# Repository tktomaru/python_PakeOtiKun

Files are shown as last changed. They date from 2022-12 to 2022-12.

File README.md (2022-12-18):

# パケ落ちくんとは？

パケ落ちくんはネットワークエミュレーターです。
Lanの途中に挟むことで、ネットワークに対し以下のことができます。

- 遅延(DELAY)
- 廃棄(LOSS)
- 破壊(CORRUPT) : PakeOtiKun4とPakeOtiKunRSが対応
- 重複(DUPLICATION) : PakeOtiKun4とPakeOtiKunRSが対応
- 並び替え(REORDERING) : PakeOtiKunRSが対応

# ブログ

# パケ落ちくんソースコード

- PakeOtiKun.py : DSAS様の作成されたものと同じものをpythonにしました
- PakeOtiKun4.py : PakeOtiKunにおいて可変抵抗が2つだったものを4つにしたものです
- PakeOtiKunRS.py : 可変抵抗は4つでロータリースイッチを追加したものです

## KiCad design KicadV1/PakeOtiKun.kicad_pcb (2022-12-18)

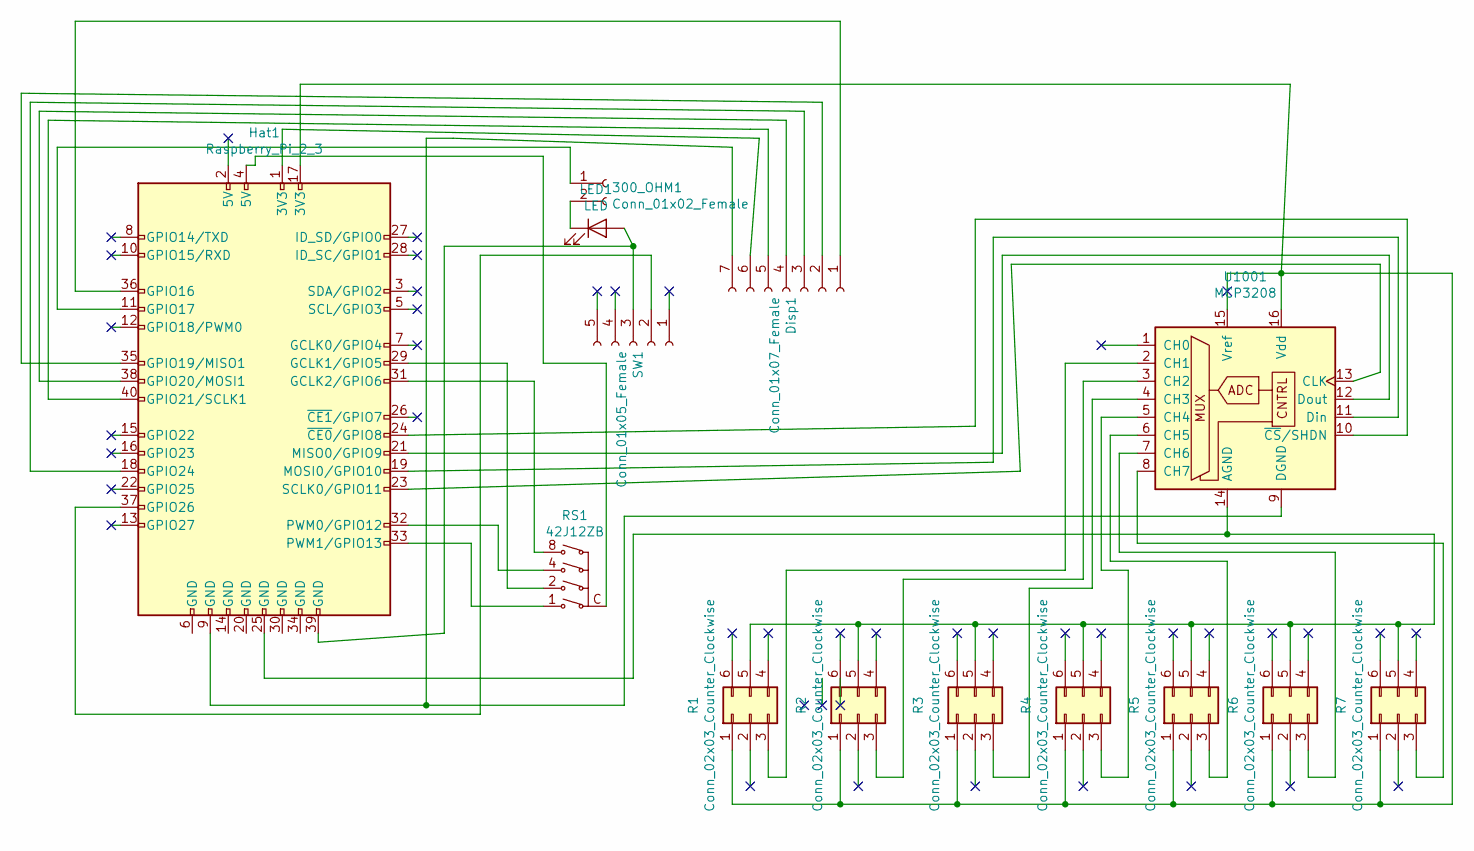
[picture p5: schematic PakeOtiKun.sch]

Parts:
300_OHM1: Conn_01x02_Female; PinSocket_1x02_P2.54mm_Vertical
Disp1: Conn_01x07_Female; PinSocket_1x07_P2.54mm_Vertical
Hat1: Raspberry_Pi_2_3; Raspi
LED1: LED; PinSocket_1x02_P2.54mm_Vertical
R1, R2, R3, R4, R5, R6, R7: Conn_02x03_Counter_Clockwise; PinSocket_2x03_P2.54mm_Vertical
RS1: 42J12ZB; RS
SW1: Conn_01x05_Female; PinSocket_1x05_P2.54mm_Vertical
U1001: MCP3208

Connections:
unnamed: 300_OHM1.1, Hat1.11 (GPIO17)
unnamed: 300_OHM1.2, LED1.1 (K)
unnamed: Disp1.1, Hat1.36 (GPIO16)
unnamed: Disp1.2, Hat1.35 (GPIO19/MISO1)
unnamed: Disp1.3, Hat1.18 (GPIO24)
unnamed: Disp1.4, Hat1.38 (GPIO20/MOSI1)
unnamed: Disp1.5, Hat1.40 (GPIO21/SCLK1)
unnamed: Disp1.6, Hat1.1 (3V3)
unnamed: Disp1.7, Hat1.9 (GND), U1001.9 (DGND)
unnamed: Hat1.4 (5V), RS1.C
unnamed: Hat1.17 (3V3), R1.1, R2.1, R3.1, R4.1, R5.1, R6.1, R7.1, U1001.15 (Vref), U1001.16 (Vdd)
unnamed: Hat1.19 (MOSI0/GPIO10), U1001.11 (Din)
unnamed: Hat1.21 (MISO0/GPIO9), U1001.12 (Dout)
unnamed: Hat1.23 (SCLK0/GPIO11), U1001.13 (CLK)
unnamed: Hat1.24 (~CE0~/GPIO8), U1001.10 (~CS~/SHDN)
unnamed: Hat1.25 (GND), R1.5, R2.5, R3.5, R4.5, R5.5, R6.5, R7.5, U1001.14 (AGND)
unnamed: Hat1.29 (GCLK1/GPIO5), RS1.2
unnamed: Hat1.31 (GCLK2/GPIO6), RS1.8
unnamed: Hat1.32 (PWM0/GPIO12), RS1.4
unnamed: Hat1.33 (PWM1/GPIO13), RS1.1
unnamed: Hat1.37 (GPIO26), SW1.2
unnamed: Hat1.39 (GND), LED1.2 (A), SW1.3
unnamed: R1.3, U1001.2 (CH1)
unnamed: R2.3, U1001.3 (CH2)
unnamed: R3.3, U1001.4 (CH3)
unnamed: R4.3, U1001.5 (CH4)
unnamed: R5.3, U1001.6 (CH5)
unnamed: R6.3, U1001.7 (CH6)
unnamed: R7.3, U1001.8 (CH7)

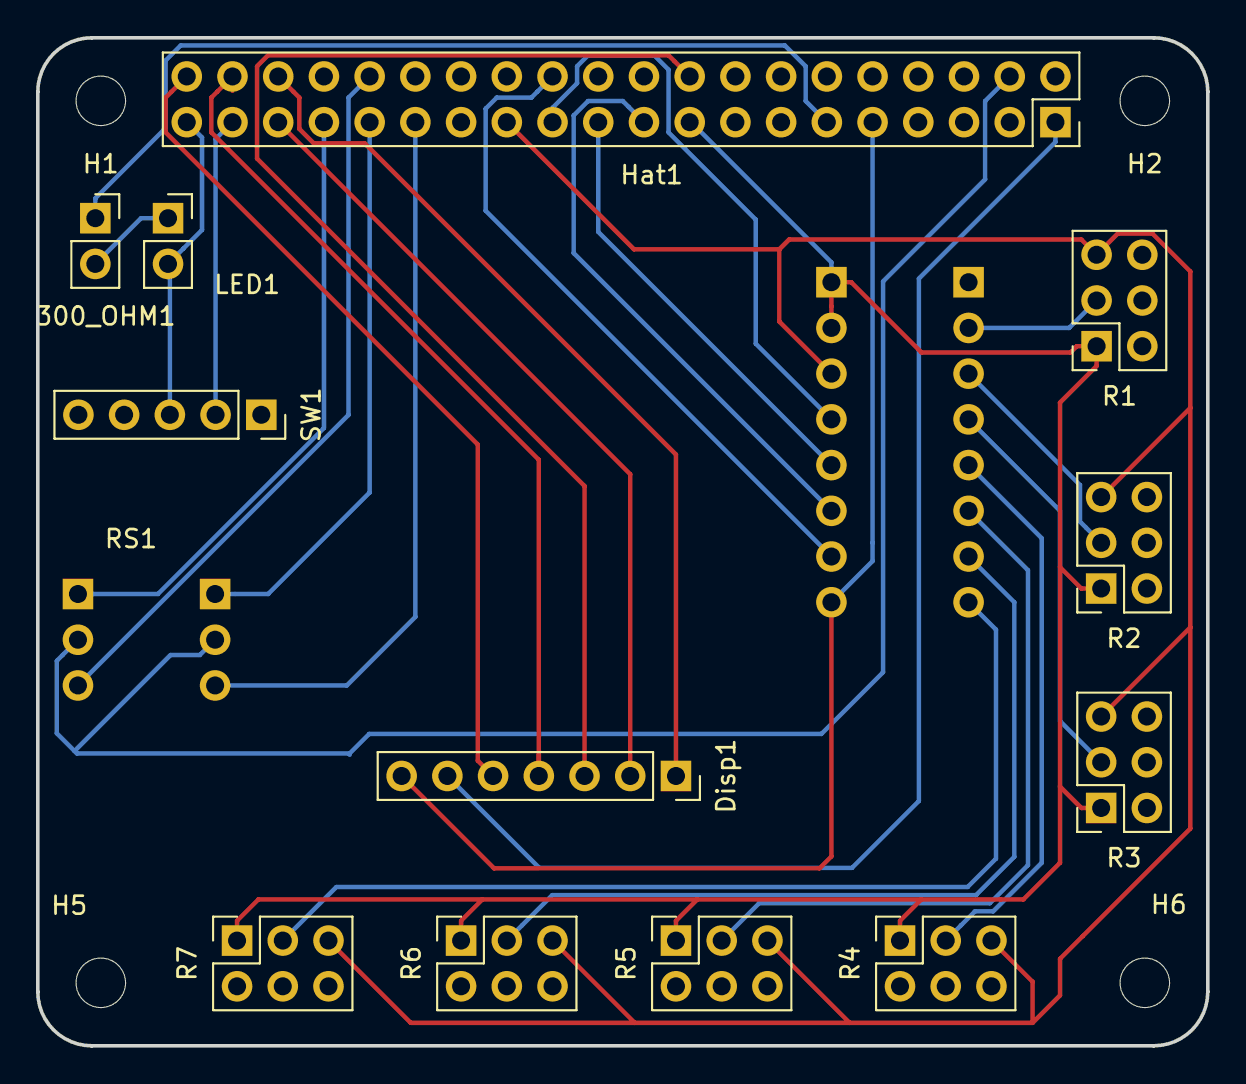
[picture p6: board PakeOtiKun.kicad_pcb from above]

Board: 2 copper layers, 65.0 x 56.0 mm, 18 parts (1 on the bottom side), 29 nets.

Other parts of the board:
H1, H2, H5, H6: MountingHole; MountingHole_2.75mm_NoPad

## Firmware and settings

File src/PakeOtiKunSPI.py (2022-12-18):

# -*- coding: utf-8 -*-
#!/usr/bin/env python

import RPi.GPIO as GPIO
import Adafruit_GPIO.SPI as SPI
import Adafruit_SSD1306
from PIL import Image, ImageDraw, ImageFont

import subprocess
import os,sys
import struct

import spidev
import time

# pip install Adafruit_GPIO  Adafruit_SSD1306 

###################################3

# SPI channel (0 or 1)
SPI_CH = 0

SPI_SS_AD = 7
SPI_SS_LCD = 8

# SPI speed (hz)
SPI_SPEED = 1000000

# GPIO number
PIN_LED = 17
PIN_SW  = 22
SW_ON   = 0

PIN_RS1 = 5
PIN_RS2 = 6
PIN_RS4 = 13
PIN_RS8 = 12

VOLUME_DELAY=0
VOLUME_LOSS =1
VOLUME_DUP=2
VOLUME_CORRUPT=3
VOLUME_REORDER1=4
VOLUME_REORDER2=5

####################################
before_delay = 0

####################################
# Raspberry Pi pin configuration
RST = 24
spi0 = SPI.SpiDev( 1, 2, max_speed_hz=SPI_SPEED)
spi0.set_mode(0)
disp = Adafruit_SSD1306.SSD1306_128_64(rst=RST, dc=19, spi=spi0)
#disp = Adafruit_SSD1306.SSD1306_128_32(rst=RST)

# Initialize library.
disp.begin()
 
# Create blank image for drawing.
# Make sure to create image with mode '1' for 1-bit color.
width = disp.width
height = disp.height
image = Image.new('1', (width, height))
 
draw = ImageDraw.Draw(image)

# Misaki Font, awesome 8x8 pixel Japanese font, can be downloaded from the following URL.
# $ wget http://www.geocities.jp/littlimi/arc/misaki/misaki_ttf_2015-04-10.zip
#font = ImageFont.truetype('/home/pi/font/misakifont/misaki_gothic.ttf', 12, encoding='unic')

# Un-comment out the following line if you want to use the default font instead of Misaki Font
font = ImageFont.load_default()

def tc_set (dev, delay, loss, dup, corrupt, reorder1, reorder2, rs):
    if rs == 1:
        if delay == 0:
           delay = 10
        cmd="sudo tc qdisc change dev %s root netem delay %dms loss %d%% reorder %d%% %d%% "%(dev, delay, loss, dup, corrupt)
    else:
        if delay == 0 and (reorder1 != 0 or reorder2 != 0):
            delay = 10
        cmd="sudo tc qdisc change dev %s root netem delay %dms loss %d%% duplicate %d%% corrupt %d%% reorder %d%% %d%%"%(dev, delay, loss, dup, corrupt, reorder1, reorder2)
    subprocess.call(cmd.split())

def tc_init (dev):
    cmd="sudo tc qdisc del dev %s root >/dev/null 2>&1"%(dev)
    subprocess.call(cmd.split())
    cmd="sudo tc qdisc add dev %s root netem delay 0ms loss 0%%"%(dev)
    subprocess.call(cmd.split())


def lcd_clear():
    # Clear display.
    #GPIO.output( SPI_SS_LCD, GPIO.LOW) 
    disp.clear()
    disp.display()
    #GPIO.output( SPI_SS_LCD, GPIO.HIGH) 

def lcd_write (delay, loss, dup, corrupt, select, reorder1, reorder2, rs):
    t1="delay %3d ms %3d %%"%(delay, reorder1)
    t2="loss  %3d %%  %3d %%"%(loss, reorder2)
    if rs == 0:
        t3="dup     %3d %%"%(dup)
    elif rs == 1:
        t3="reorder %3d %%"%(dup)
    else:
        t3="dup     %3d %%"%(dup)

    if rs == 0:
        t4="corrup  %3d %%"%(corrupt)
    elif rs == 1:
        t4="reorder %3d %%"%(corrupt)
    else:
        t4="corrup  %3d %%"%(corrupt)


    if select == 0:
        t1="delay %3d ms %3d %%"%(delay, reorder1)
    if select == 1:
        t2="loss  %3d %%  %3d %%"%(loss, reorder2)
    if select == 2:
        if rs == 0:
            t3="dup     %3d %%"%(dup)
        elif rs == 1:
            t3="reorder %3d %%"%(dup)
        else:
            t3="dup     %3d %%"%(dup)
    if select == 3:
        if rs == 0:
            t4="corrup  %3d %%"%(corrupt)
        elif rs == 1:
            t4="reorder %3d %%"%(corrupt)
        else:
            t4="corrup  %3d %%"%(corrupt)

    #GPIO.output( SPI_SS_LCD, GPIO.LOW) 
    image = Image.new('1', (width, height))
    draw = ImageDraw.Draw(image)

    x=0
    y=0
    draw.text((x,y), t1, font=font,  fill=255)
    y+=16
    draw.text((x,y), t2, font=font,  fill=255)
    y+=16
    draw.text((x,y), t3, font=font,  fill=255)
    y+=16
    draw.text((x,y), t4, font=font,  fill=255)

    disp.image(image)
    disp.display()
    #GPIO.output( SPI_SS_LCD, GPIO.HIGH) 

class MCP3208:
        def __init__(self, spi_channel=0):
                self.spi_channel = spi_channel
                self.conn = SPI.SpiDev(0, spi_channel, SPI_SPEED)
                self.conn.set_mode(0)
                self.conn.set_bit_order(SPI.MSBFIRST)
                #self.conn.max_speed_hz = SPI_SPEED # 1MHz

        def __del__( self ):
                self.close

        def close(self):
                if self.conn != None:
                        self.conn.close
                        self.conn = None

        def bitstring(self, n):
                s = bin(n)[2:]
                return '0'*(8-len(s)) + s

        def read(self, adc_channel=0):
                # build command
                cmd  = 128 # start bit
                cmd +=  64 # single end / diff
                cmd += ((adc_channel & 0x07) << 3)
                #if adc_channel % 2 == 1:
                #        cmd += 8
                #if (adc_channel/2) % 2 == 1:
                #        cmd += 16
                #if (adc_channel/4) % 2 == 1:
                #        cmd += 32

                # send & receive data
                #reply_bytes = self.conn.xfer2([cmd, 0, 0, 0])
                reply_bytes = self.conn.transfer([cmd, 0, 0, 0])

                #
                reply_bitstring = ''.join(self.bitstring(n) for n in reply_bytes)
                # print reply_bitstring

                # see also... http://akizukidenshi.com/download/MCP3204.pdf (page.20)
                #reply = reply_bitstring[5:19]
                #return int(reply, 2)
                reply = (reply_bytes[0] & 0x01) << 11
                reply |= reply_bytes[1] << 3
                reply |= reply_bytes[2] >> 5
                return (reply & 0x0FFF)

def RS_Analysis( rs1, rs2, rs4, rs8 ):
        rs = 0
        if rs1 == 0 and rs2 == 0 and rs4 == 0 and rs8 == 0 :
            rs = 0
        if rs1 == 1 and rs2 == 0 and rs4 == 0 and rs8 == 0 :
            rs = 1
        if rs1 == 0 and rs2 == 1 and rs4 == 0 and rs8 == 0 :
            rs = 2
        if rs1 == 1 and rs2 == 1 and rs4 == 0 and rs8 == 0 :
            rs = 3
        if rs1 == 0 and rs2 == 0 and rs4 == 1 and rs8 == 0 :
            rs = 4
        if rs1 == 1 and rs2 == 0 and rs4 == 1 and rs8 == 0 :
            rs = 5
        if rs1 == 0 and rs2 == 1 and rs4 == 1 and rs8 == 0 :
            rs = 6
        if rs1 == 1 and rs2 == 1 and rs4 == 1 and rs8 == 0 :
            rs = 7
        if rs1 == 0 and rs2 == 0 and rs4 == 0 and rs8 == 1 :
            rs = 8
        if rs1 == 1 and rs2 == 0 and rs4 == 0 and rs8 == 1 :
            rs = 9
        #print("RW")
        #print(rs)
        return rs

def hosei100( l ):
        l = round(++l / 2 / 20.47)
        if l < 3:
            l=0
        if l >= 98:
            l = 100
        return l

def hosei2000( l ):
        global before_delay
        l = round(++l / 2.048 ) # 4096
        # if ( l >= 3 and ((before_delay - 10) <= l) and (l <= (before_delay + 10 ))):
        # l = before_delay
        # else:
        #     before_delay = l
        if l < 3:
            l=0
        if l >= 1990:
            l=2000
        return l

def hosei2048( l ):
        l = round(++l / 2 )
        if l < 3:
            l=0
        return l

def burst_mode():
    for n in range(devnum):
        tc_set( devices[n], 0, 100, 0, 0, 0, 0, 0)
    lcd_clear()
    image = Image.new('1', (width, height))
    draw = ImageDraw.Draw(image)
    draw.text((0,0), "burst  mode  ", font=font,  fill=255)
    disp.image(image)
    disp.display()
    GPIO.output(PIN_LED,  1 )
    while True:
        #print("burst mode")
        sw=GPIO.input( PIN_SW )
        if sw != SW_ON:
            break
        #time.sleep(1)

if __name__=="__main__":
    spi = MCP3208(SPI_CH)

    # Write two lines of text.
    x=0
    y=0
    for str in [ u'booting' ]:
        draw.text((x,y), str, font=font,  fill=255)
        y+=16

    # rotate 180
    #disp.com(0xa0)
    #disp.com(0xc0)

    devices = ["eth0", "eth1"];
    devnum  = 2;
    for dev in devices:
        tc_init(dev)
    delay =  -1 # for display out
    loss = 0
    dup  = 0
    corrupt = 0
    grs = 0
    reorder1 = 0
    reorder2 = 0
    print("GPIO.setup LED")
    GPIO.setmode(GPIO.BCM)
    GPIO.setup( PIN_LED , GPIO.OUT )
    print("GPIO.setup SW")
    GPIO.setup( PIN_SW, GPIO.IN, pull_up_down=GPIO.PUD_UP )
    GPIO.setup( PIN_RS1, GPIO.IN )
    GPIO.setup( PIN_RS2, GPIO.IN )
    GPIO.setup( PIN_RS4, GPIO.IN )
    GPIO.setup( PIN_RS8, GPIO.IN )

    #time.sleep(2)

    while (1):
        sw=GPIO.input( PIN_SW )
        if sw == SW_ON:
            burst_mode()
            delay = -1 # for display out
        rs1=GPIO.input( PIN_RS1 )
        rs2=GPIO.input( PIN_RS2 )
        rs4=GPIO.input( PIN_RS4 )
        rs8=GPIO.input( PIN_RS8 )

        rs = RS_Analysis( rs1, rs2, rs4, rs8 )
        #print(rs)

        #print("delay >>")

        d = hosei2000( spi.read(VOLUME_DELAY)  )
        l = hosei100( spi.read(VOLUME_LOSS) )
        c = hosei100( spi.read(VOLUME_CORRUPT) )
        p = hosei100( spi.read(VOLUME_DUP) )
        r1 = hosei100( spi.read(VOLUME_REORDER1) )
        r2 = hosei100( spi.read(VOLUME_REORDER2) )

        if (d != delay):
           gselect = 0
        if (l != loss):
           gselect = 1
        if (p != dup):
           gselect = 2
        if (c != corrupt):
           gselect = 3

        if (d != delay or l != loss or p != dup or c != corrupt or r1 != reorder1 or r2 != reorder2 or rs != grs):
            delay = d
            loss = l
            dup = p
            corrupt = c
            grs = rs
            reorder1 = r1
            reorder2 = r2
            for n in range(devnum):
                tc_set(devices[n], delay, loss, dup, corrupt, reorder1, reorder2, grs)
            lcd_clear()
            lcd_write (delay, loss, dup, corrupt, gselect, reorder1, reorder2, grs)
        if delay != 0 or loss != 0 or dup != 0 or corrupt != 0 or reorder1 != 0 or reorder2 != 0:
            GPIO.output(PIN_LED,  1 )
        else:
            GPIO.output(PIN_LED,  0 )

       # time.sleep(2)

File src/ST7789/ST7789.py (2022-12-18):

# ST7789 IPS LCD (240x240) driver
import numbers
import time
import numpy as np

from PIL import Image
from PIL import ImageDraw

import Adafruit_GPIO as GPIO
import Adafruit_GPIO.SPI as SPI

SPI_CLOCK_HZ = 40000000 # 40 MHz

# Constants for interacting with display registers.
ST7789_TFTWIDTH    = 240
ST7789_TFTHEIGHT   = 240

ST7789_NOP         = 0x00
ST7789_SWRESET     = 0x01
ST7789_RDDID       = 0x04
ST7789_RDDST       = 0x09
ST7789_RDDPM       = 0x0A
ST7789_RDDMADCTL   = 0x0B
ST7789_RDDCOLMOD   = 0x0C
ST7789_RDDIM       = 0x0D
ST7789_RDDSM       = 0x0E
ST7789_RDDSDR      = 0x0F

ST7789_SLPIN       = 0x10
ST7789_SLPOUT      = 0x11
ST7789_PTLON       = 0x12
ST7789_NORON       = 0x13

ST7789_INVOFF      = 0x20
ST7789_INVON       = 0x21
ST7789_GAMSET      = 0x26
ST7789_DISPOFF     = 0x28
ST7789_DISPON      = 0x29
ST7789_CASET       = 0x2A
ST7789_RASET       = 0x2B
ST7789_RAMWR       = 0x2C
ST7789_RAMRD       = 0x2E

ST7789_PTLAR       = 0x30
ST7789_VSCRDEF     = 0x33
ST7789_TEOFF       = 0x34
ST7789_TEON        = 0x35
ST7789_MADCTL      = 0x36
ST7789_VSCRSADD    = 0x37
ST7789_IDMOFF      = 0x38
ST7789_IDMON       = 0x39
ST7789_COLMOD      = 0x3A
ST7789_RAMWRC      = 0x3C
ST7789_RAMRDC      = 0x3E

ST7789_TESCAN      = 0x44
ST7789_RDTESCAN    = 0x45

ST7789_WRDISBV     = 0x51
ST7789_RDDISBV     = 0x52
ST7789_WRCTRLD     = 0x53
ST7789_RDCTRLD     = 0x54
ST7789_WRCACE      = 0x55
ST7789_RDCABC      = 0x56
ST7789_WRCABCMB    = 0x5E
ST7789_RDCABCMB    = 0x5F

ST7789_RDABCSDR    = 0x68

ST7789_RDID1       = 0xDA
ST7789_RDID2       = 0xDB
ST7789_RDID3       = 0xDC

ST7789_RAMCTRL     = 0xB0
ST7789_RGBCTRL     = 0xB1
ST7789_PORCTRL     = 0xB2
ST7789_FRCTRL1     = 0xB3

ST7789_GCTRL       = 0xB7
ST7789_DGMEN       = 0xBA
ST7789_VCOMS       = 0xBB

ST7789_LCMCTRL     = 0xC0
ST7789_IDSET       = 0xC1
ST7789_VDVVRHEN    = 0xC2

ST7789_VRHS        = 0xC3
ST7789_VDVSET      = 0xC4
ST7789_VCMOFSET    = 0xC5
ST7789_FRCTR2      = 0xC6
ST7789_CABCCTRL    = 0xC7
ST7789_REGSEL1     = 0xC8
ST7789_REGSEL2     = 0xCA
ST7789_PWMFRSEL    = 0xCC

ST7789_PWCTRL1     = 0xD0
ST7789_VAPVANEN    = 0xD2
ST7789_CMD2EN      = 0xDF5A6902
ST7789_PVGAMCTRL   = 0xE0
ST7789_NVGAMCTRL   = 0xE1
ST7789_DGMLUTR     = 0xE2
ST7789_DGMLUTB     = 0xE3
ST7789_GATECTRL    = 0xE4
ST7789_PWCTRL2     = 0xE8
ST7789_EQCTRL      = 0xE9
ST7789_PROMCTRL    = 0xEC
ST7789_PROMEN      = 0xFA
ST7789_NVMSET      = 0xFC
ST7789_PROMACT     = 0xFE

# Colours for convenience
ST7789_BLACK       = 0x0000 # 0b 00000 000000 00000
ST7789_BLUE        = 0x001F # 0b 00000 000000 11111
ST7789_GREEN       = 0x07E0 # 0b 00000 111111 00000
ST7789_RED         = 0xF800 # 0b 11111 000000 00000
ST7789_CYAN        = 0x07FF # 0b 00000 111111 11111
ST7789_MAGENTA     = 0xF81F # 0b 11111 000000 11111
ST7789_YELLOW      = 0xFFE0 # 0b 11111 111111 00000
ST7789_WHITE       = 0xFFFF # 0b 11111 111111 11111


def color565(r, g, b):
    """Convert red, green, blue components to a 16-bit 565 RGB value. Components
    should be values 0 to 255.
    """
    return ((r & 0xF8) << 8) | ((g & 0xFC) << 3) | (b >> 3)

def image_to_data(image):
    """Generator function to convert a PIL image to 16-bit 565 RGB bytes."""
    # NumPy is much faster at doing this. NumPy code provided by:
    # Keith (https://www.blogger.com/profile/02555547344016007163)
    pb = np.array(image.convert('RGB')).astype('uint16')
    color = ((pb[:,:,0] & 0xF8) << 8) | ((pb[:,:,1] & 0xFC) << 3) | (pb[:,:,2] >> 3)
    return np.dstack(((color >> 8) & 0xFF, color & 0xFF)).flatten().tolist()

class ST7789(object):
    """Representation of an ST7789 IPS LCD."""

    def __init__(self, spi, mode=3, rst=27, dc=25, led=27, gpio=None, width=ST7789_TFTWIDTH,
        height=ST7789_TFTHEIGHT):
        """Create an instance of the display using SPI communication.  Must
        provide the GPIO pin number for the D/C pin and the SPI driver.  Can
        optionally provide the GPIO pin number for the reset pin as the rst
        parameter.
        """
        self._spi = spi
        self._rst = rst
        self._dc = dc
        self._led = led
        self._gpio = gpio
        self.width = width
        self.height = height
        if self._gpio is None:
            self._gpio = GPIO.get_platform_gpio()
        # Set DC as output.
        self._gpio.setup(dc, GPIO.OUT)
        # Setup reset as output (if provided).
        if rst is not None:
            self._gpio.setup(rst, GPIO.OUT)
        # Turn on the backlight LED
        self._gpio.setup(led, GPIO.OUT)
        self._gpio.setup(led, GPIO.HIGH)
        # Set SPI to mode 0, MSB first.
        spi.set_mode(mode)
        spi.set_bit_order(SPI.MSBFIRST)
        spi.set_clock_hz(SPI_CLOCK_HZ)
        # Create an image buffer.
        self.buffer = Image.new('RGB', (width, height))

    def send(self, data, is_data=True, chunk_size=4096):
        """Write a byte or array of bytes to the display. Is_data parameter
        controls if byte should be interpreted as display data (True) or command
        data (False).  Chunk_size is an optional size of bytes to write in a
        single SPI transaction, with a default of 4096.
        """
        # Set DC low for command, high for data.
        self._gpio.output(self._dc, is_data)
        # Convert scalar argument to list so either can be passed as parameter.
        if isinstance(data, numbers.Number):
            data = [data & 0xFF]
        # Write data a chunk at a time.
        for start in range(0, len(data), chunk_size):
            end = min(start+chunk_size, len(data))
            self._spi.write(data[start:end])

    def command(self, data):
        """Write a byte or array of bytes to the display as command data."""
        self.send(data, False)

    def data(self, data):
        """Write a byte or array of bytes to the display as display data."""
        self.send(data, True)

    def reset(self):
        """Reset the display, if reset pin is connected."""
        if self._rst is not None:
            self._gpio.set_high(self._rst)
            time.sleep(0.100)
            self._gpio.set_low(self._rst)
            time.sleep(0.100)
            self._gpio.set_high(self._rst)
            time.sleep(0.100)

    def _init(self):
        # Initialize the display.  Broken out as a separate function so it can
        # be overridden by other displays in the future.

        time.sleep(0.010)
        self.command(0x11)
        time.sleep(0.150)

        self.command(0x36)
        self.data(0x00)

        self.command(0x3A)
        self.data(0x05)

        self.command(0xB2)
        self.data(0x0C)
        self.data(0x0C)

        self.command(0xB7)
        self.data(0x35)

        self.command(0xBB)
        self.data(0x1A)

        self.command(0xC0)
        self.data(0x2C)

        self.command(0xC2)
        self.data(0x01)

        self.command(0xC3)
        self.data(0x0B)

        self.command(0xC4)
        self.data(0x20)

        self.command(0xC6)
        self.data(0x0F)
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

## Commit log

2022-12-18 開発／初期コミット
    [PakeOtiKun-B_Cu.gbl, PakeOtiKun-B_Cu.gbr, PakeOtiKun-B_Mask.gbr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]
2022-12-18 開発／README.mdを修正
2023-08-05 動かないV2を削除
    [PakeOtiKun-B_Cu.gbl, PakeOtiKun-B_Mask.gbs, PakeOtiKun-B_Paste.gbp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]
